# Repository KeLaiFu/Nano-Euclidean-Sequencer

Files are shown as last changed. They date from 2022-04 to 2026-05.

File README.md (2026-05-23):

# Nano-Euclidean-Sequencer
Eurorack adaption of an original kosmo module by instructables.com/member/ljbrackney. Current code is operational but needs some fine tuning.   

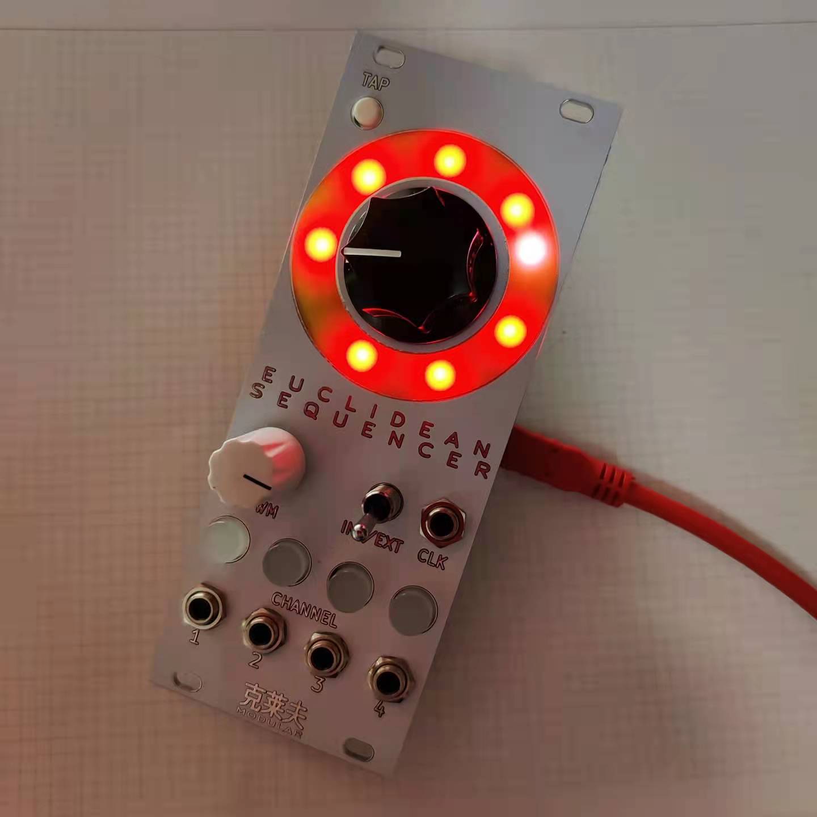
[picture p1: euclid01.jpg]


Current Status:
Hardware - finished.
Software - almost finished.

NOTE! If anyone wants to build this, please post a pull request or whatever they are here and I will dig up the latest firmware.

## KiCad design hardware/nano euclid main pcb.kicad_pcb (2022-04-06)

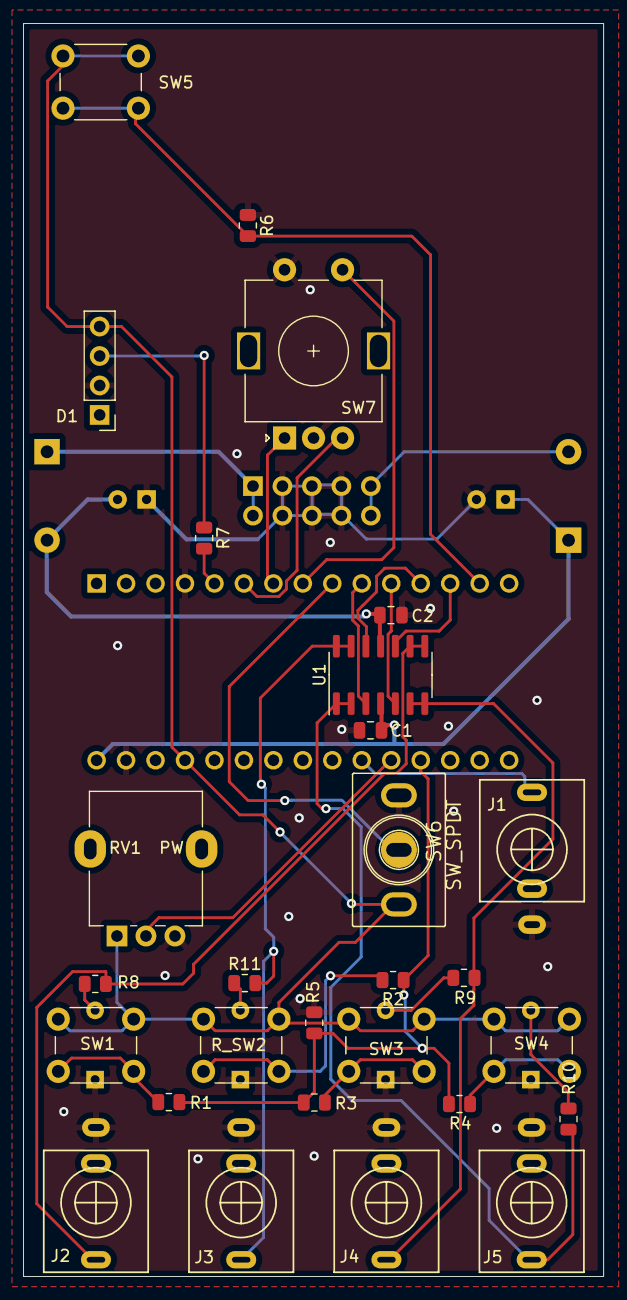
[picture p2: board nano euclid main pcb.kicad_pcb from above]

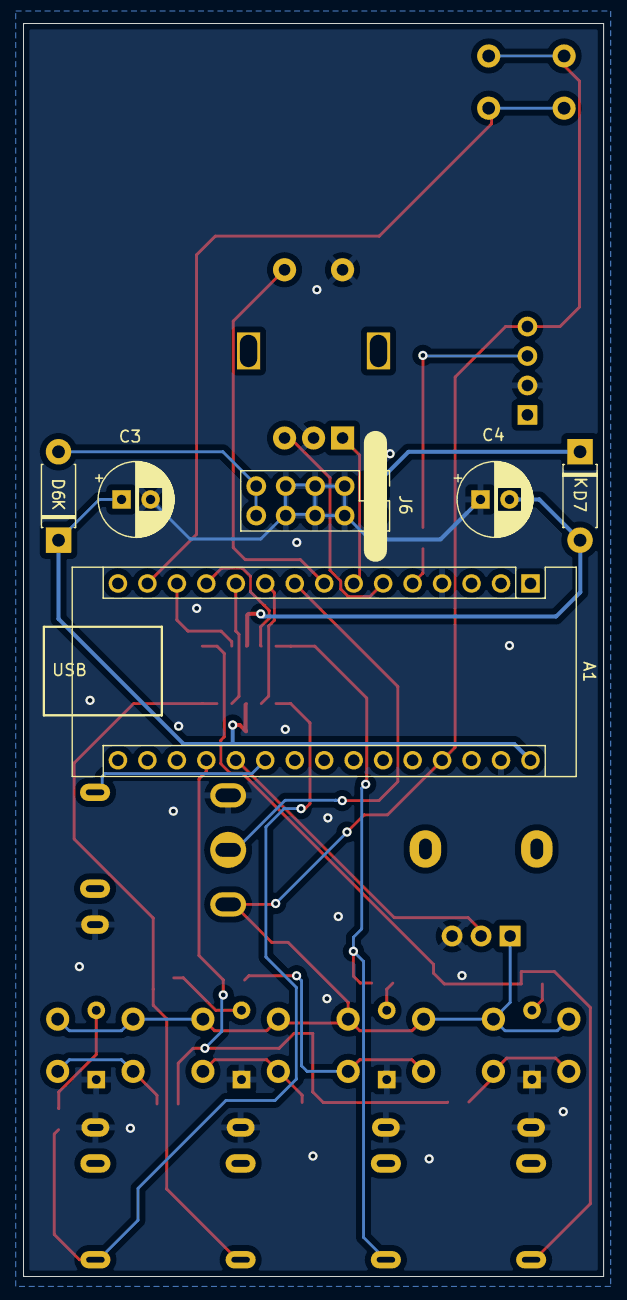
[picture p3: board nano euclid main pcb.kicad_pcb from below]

Board: 2 copper layers, 50.0 x 108.0 mm, 34 parts (6 on the bottom side), 32 nets.

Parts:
A1: Arduino_Nano_v3.x; Arduino_Nano
C1, C2: 0.1uF; C_0805_2012Metric
C3, C4: 10uF; CP_Radial_D6.3mm_P2.50mm
D1: NeoPixel_THT; PinHeader_1x04_P2.54mm_Vertical
D6, D7: 1N5817; D_DO-41_SOD81_P7.62mm_Horizontal
J1: CLOCK; PJ398SM
J2, J3, J4, J5: AudioJack2_Ground; PJ398SM
J6: Synth_power_2x5; PinHeader_2x05_P2.54mm_Vertical
R1, R2, R3, R4, R5, R6, R7, R8, R9, R10, R11: R; R_0805_2012Metric
RV1  PW: R_Potentiometer; Potentiometer_Alpha_RD901F-40-00D_Single_Vertical
R_SW2: SW_Push; SW_PUSH_LED_6mm
SW1, SW3, SW4: SW_Push; SW_PUSH_LED_6mm
SW5: SW_Push; SW_PUSH_6mm
SW6: SW_SPDT; SPDT_KIT
SW7: RotaryEncoder_Switch; RotaryEncoder_Alps_EC11E-Switch_Vertical_H20mm
U1: TL074; SOIC-14_3.9x8.7mm_P1.27mm

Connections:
+12V: A1.30 (VIN), C1.1, C3.1, D6.1 (K), U1.4 (V+)
-12V: C2.1, C4.2, D7.2 (A), U1.11 (V-)
GND: A1.4 (GND), A1.29 (GND), C1.2, C2.2, C3.2, C4.1, D1.2 (GND), J1.S, J2.S, J3.S, J4.S, J5.S, J6.3 (GND), J6.4 (GND), J6.5 (GND), J6.6 (GND), J6.7 (GND), J6.8 (GND), R5.2, R6.1, RV1 PW.3, R_SW2.4 (K), SW1.4 (K), SW3.4 (K), SW4.4 (K), SW6.1 (A), SW7.C, SW7.S2
unnamed: A1.5 (D2), R7.2
unnamed: A1.6 (D3), SW7.B
unnamed: A1.7 (D4), SW7.A
unnamed: A1.8 (D5), SW7.S1
unnamed: A1.9 (D6), SW6.2 (B)
unnamed: A1.10 (D7), U1.3 (+)
unnamed: A1.11 (D8), U1.5 (+)
unnamed: A1.12 (D9), U1.12 (+)
unnamed: A1.13 (D10), U1.10 (+)
unnamed: A1.14 (D11), R6.2, SW5.2
unnamed: A1.19 (A0), R1.1, R2.1, R3.1, R4.1, R5.1
unnamed: A1.20 (A1), RV1 PW.2
unnamed: A1.21 (A2), J1.T
unnamed: A1.27 (+5V), D1.4 (DIN), RV1 PW.1, R_SW2.1, SW1.1, SW3.1, SW4.1, SW5.1, SW6.3 (C)
unnamed: D1.3 (VDD), R7.1
unnamed: D6.2 (A), J6.9 (+12V), J6.10 (+12V)
unnamed: D7.1 (K), J6.1 (-12V), J6.2 (-12V)
unnamed: J2.T, R8.1, U1.8, U1.9 (-)
unnamed: J3.T, R11.2, U1.13 (-), U1.14
unnamed: J4.T, R9.2, U1.6 (-), U1.7
unnamed: J5.T, R10.2, U1.1, U1.2 (-)
unnamed: R1.2, SW1.2
unnamed: R2.2, R_SW2.2
unnamed: R3.2, SW3.2
unnamed: R4.2, SW4.2
unnamed: R8.2, SW1.3 (A)
unnamed: R9.1, SW3.3 (A)
unnamed: R10.1, SW4.3 (A)
unnamed: R11.1, R_SW2.3 (A)

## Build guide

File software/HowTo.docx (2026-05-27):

Compile, upload and run the code one time with the “Pre.ino” one .

This will result in the nano writing 16 patches to its EEPROM.

One patch will contain a pattern, the others are empty patches.

Next use the “After.ino” and compile, upload and run the code. This will program the Euclidean sequencer code into the nano which will be run each time you start up the nano.

The nano will read the patches from memory each time it starts and chooses the patch you saved last.

Upon startup the sequencer is in 'Pattern Length / Tempo Mode'.

When pressing the rotary encoder you can switch to the second mode, 'Num Pulse Mode'.

Press it again and the mode is 'Rotate Mode'.

Press again and the mode returns to 'Pattern Length / Tempo Mode'.

In 'Pattern Mode' rotating the encoder will increase or decrease the pattern length of the chosen trigger channel. Each time you change the length of the pattern a new fitting Euclidean pattern is generated depending on the number of pulses chosen (see below) for this pattern. Rotating the dial with the tap tempo / shift button pressed at the same time, will allow for changing tempo of the sequencer's internal clock.

In 'Num Pulse Mode' the encoder can be used to set the number of trigger pulses for the chosen trigger channel. The pulses will follow a Euclidean pattern.

In 'Rotate Mode' it is possible to shift the trigger pulse pattern accross the total length of the pattern.

Pressing the shift button and the rotary switch at the same time (…fill mode) will select the 'Program Mode'.

Using the rotary encoder's knob 1 of 16 memory cells can be selected.

- Pressing the trigger channel D button will store the current pattern of the selected trigger channel to the corresponding memory cell.

- Pressing the trigger channel A button will recall the patch pattern stored in the EEPROM memory cell and store it in the sequencer's active memory at the patch number selected with the rotary dial.

- Pressing the trigger channel B button will clear the patch in the eeprom the rotary encoder is set to. The pattern already in the working memory however will not be changed. Don't forget to save it if you like it. The LEDs will light up red for the locations containing a patch and green for the locations that are cleared. When in 'Program Mode' pressing the rotary switch will switch to 'Pattern Length / Tempo Mode'

To exit Programm mode press the main encoder.

Changed the slowest loop time to 2 sec per step for more slower beats possible.

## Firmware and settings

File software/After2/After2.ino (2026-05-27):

  /*
   *                                                                      
   *   Program:      Euclidean Rhythm Generator Kosmo/Eurorack  
   *   Author:       L J Brackney,                              
   *   Organization: Suncoast Polytechnical High School         
   *   Version:      1.0                                        
   *   Date:         11/21/2021                                 
   *                                                            
   *   Adapted by Jos Bouten, Jan ... Apr 2022              
   *   Added support for shift button, clock out, 4 function inputs
   *   - Added variable pattern length                        
   *   - To change the tempo the shift/tap tempo button needs to be pressed while   
   *     the rotary encoder is rotated.                                      
   *   - Changed all channel dependent variables into arrays.
   *   - Used capitals for constants, camel case for variables and function calls
   *   - Setting the speed depends on pressing the tap tempo button.
   *   - While setting the speed, the pattern leds show a white background pattern.
   *   - Added storing, recalling and clearing of patches in EEPROM.
   *   - The channel chosen last will be recalled on startup.
   *  2022-04-27: Whenever you change the pattern length, or change the number of Euclidean Rhythm pulses,
   *     a new euclidean pattern is generated and this pattern is started from its starting position
   *     for the active pattern.
   * 2022-04-29: The mode from which a jump into program mode is made is restored when leaving program mode.
   * 2022-05-05: Code adapted to function inputs using negative logic.
   *   
   *  Compile, upload and run the code one time with the INITIALIZE flag set.
   *  This will result in the nano writing 16 patches to its EEPROM.
   *  One patch will contain a pattern, the others are empty patches.
   *  Next comment out the line "#define INITIALIZE 1" and compile, upload 
   *  and run the code. This will program the Euclidean sequencer code into the nano 
   *  which will be run each time you start up the nano. The nano will read the patches
   *  from memory each time it starts and chooses the patch you saved last.
   *  
   *  Upon startup the sequencer is in 'Pattern Length / Tempo Mode'. When pressing the rotary encoder you can 
   *  switch to the second mode, 'Num Pulse Mode'. Press it again and the mode is 'Rotate Mode'.
   *  Press again and the mode returns to 'Pattern Length / Tempo Mode'.
   *  
  *  In 'Pattern Mode' rotating the encoder will increase or decrease the pattern length of the chosen trigger channel.
   *  Each time you change the length of the pattern a new fitting Euclidean pattern is generated depending on
   *  the number of pulses chosen (see below) for this pattern.
   *  Rotaring the dial with the tap tempo / shift button pressed at the same time, will allow for changing 
   *  tempo of the sequencer's internal clock. 
   *  In 'Num Pulse Mode' the encoder can be used to set the number of trigger pulses for the chosen trigger channel. 
   *  The pulses will follow a Euclidean pattern.
   *  In 'Rotate Mode' it is possible to shift the trigger pulse pattern accross the total length of the pattern.
   *  
   *  Pressing the shift button and the rotary switch at the same time will select the 'Program Mode'.
   *  Using the rotary encoder's knob 1 of 16 memory cells can be selected.
   *  Pressing the trigger channel D button will store the current pattern of the selected trigger channel to the corresponding memory cell.
   *  Pressing the trigger channel A button will recall the patch pattern stored in the EEPROM memory cell and store it in 
   *  the sequencer's active memory at the patch number selected with the rotary dial.
   *  Pressing the trigger channel B button will clear the patch in the eeprom the rotary encoder is set to. 
   *  The pattern already in the working memory however will not be changed. Don't forget to save it is you like it.
   *  
   *  The leds will light up red for the locations containing a patch and green for the locations that are cleared.
   *  When in 'Program Mode' pressing the rotary switch will switch to 'Pattern Length / Tempo Mode'.
   *  
   *  2022-02-27: some changes to hardware and software
   *  - deactivated pattern length change menu because this is hardly ever used and 
   *    is a nuisance to have to click through
   *  - added tempo change to rotate and pulse number menu.
   *  - adapted ext clock in and func in to positive logic after hardware change
   *  - changed the range of the pulse width knob so that the output pulses range from 
   *    about 10% to 99% of the clock cyle time
   *  - changed the duty cycle of the clock out to be fixed at 50%
   */

// Show some debug info on the serial port.
#define DEBUG 1

// Activate this if you allow pattern length change
// #define ALLOW_PATTERN_LENGTH_CHANGE 1


// Run program once using INITIALIZE to set some initial values in the EEPROM
//#define INITIALIZE 1

// Use the switches below to make the brightness of the neopixel oscillate.

#define LED_FX 1 // Oscillate LEDs in all modes except PROGRAM_MODE.
//#define LED_FX_BLACK 1 // When set the intensity will fall back to 0, otherwise to 1.
//#define PATCH_MEMORY_LED_FX 1 // Also oscillate LED intensity in PROGRAM_MODE

#include <Adafruit_NeoPixel.h>    // Include Adafruit_NeoPixel library
#include <Encoder.h>              // Include rotary encoder library
#include <EEPROM.h>

/* 
    EEPROM memory layout:
    0: selectedTriggerChannel
    1: default programNumber
    2: memoryCellsInUse
    3: delayTime
    4: 16 patches:
     - pulses[5]
     - channelPattern[5]
     - patternLength[5]

*/

Encoder myEnc(3, 4);              // Attach rotary encoder to digital pins 3 and 4

#define PIXEL_PIN      2          // Attach NeoPixel ring to digital pin 2
#define PROG_PIN       5          // Attach rotary encoder switch to digital pin 5
#define CLOCK_SOURCE_PIN 6          // Attach external clock select switch to digital pin 6
#define TRIG_D_PIN     7          // Attach the four drum/voice trigger output pins to 
#define TRIG_C_PIN     8          //   digital pins 7-10.  I mixed up two wires when
#define TRIG_B_PIN     9          //   assembling the modules, and it was easier to
#define TRIG_A_PIN    10          //   swap pins 7 and 10 than to resolder things. :)
#define BUTTON_PIN    A0          // The trigger select buttons are on a voltage divider attached to A0
#define PWM_POT_PIN   A1          // The pulse width potentiometer is attached to analog pin A1
#define RESET_PIN     12          // RESET_PIN CV in on D12
#define NUM_CHANNELS 4

#define SHIFT_PIN     11          // Shift Function button on D11 
#define ON LOW
#define OFF HIGH

// Modes you can choose by pressing the rotary encoder's button.
#define PATTERN_LENGTH_MODE 1 // also used as "pulse length mode"
#define NUM_PULSE_MODE      2
#define ROTATE_MODE         3
#define PROGRAM_MODE        4 // Allows to store patterns in EEPROM or to recall them. This mode can only be reached 
                              // pressing the shift button AND the rotary encoder button.
#define MAX_MODE            3 // Note, we do not count PROGRAM_MODE here.         

#define F1_PIN A7            // Function F1 in
#define F2_PIN A6            // Function F2 in
#define F3_PIN A5            // Function F3 in
#define F4_PIN A4            // Function F4 in
#define SEQ_CLOCK_OUT_PIN A3 // Sequencer clock out (whether internal or from external source)
#define EXT_CLOCK_IN_PIN  A2 // Ext Clock in

#define HALF_DAC_RANGE 500

#define NUM_NEOP_LEDS 16     // The number of LEDs in the neopixel wheel.

#define MAX_DELAY_TIME 1000   // Limit the slowest loop time to 1 sec per step.
                             // Change if you want slower tempos.          

#define NR_OF_MEMORY_CELLS NUM_NEOP_LEDS

#define EEPROM_BASE_ADDRESS 0

#define TRIG_A 3
#define TRIG_B 2
#define TRIG_C 1
#define TRIG_D 0

#define MAX_ADC_VALUE 1000 // This number was determined empirically.

#define CHECK_BIT(var, pos) ((var) & (1 << (pos)))

char CHANNEL_NAMES[4] = {'D', 'C', 'B', 'A'};

char msg[255];

static int step[4];               // The active step for each trigger channel.
struct Patch {
  int pulses[4];                  // The number of pulses to be generated for each of the 4 triggers.
  int patternLength[4];           // The pattern length for each trigger output.
  unsigned int channelPattern[4]; // The pattern of Euclidean distributed pulses,
};

Patch emptyPatch;
Patch currentPatch;               // The patch the sequencer is playing.

Patch patches[NR_OF_MEMORY_CELLS];
unsigned int delayTime  = 125;    // The time between steps persists in each loop.
unsigned int memoryCellsInUse = 0;
int chosenPatchNumber = 0;
int candidatePatchNumber = 0;
int selectedTriggerChannel = -1;

Adafruit_NeoPixel pixels(NUM_NEOP_LEDS, PIXEL_PIN, NEO_GRB + NEO_KHZ800); // Set up the NeoPixel ring

// Fill the dots one after the other with a color.
void colorWipe(uint32_t c, uint8_t wait, int direction = 0) {
  if (direction == 0) {
    for (uint16_t i = 0; i < pixels.numPixels(); i++) {
      pixels.setPixelColor(i, c);
      pixels.show();
      delay(wait);
    } 
  } else {
    for (uint16_t i = pixels.numPixels()-1; i > 0; i--) {
      pixels.setPixelColor(i, c);
      pixels.show();
      delay(wait);
    }
  }
}

// The Euclid function returns an unsigned integer whose bits reflect a Euclidean rhythm of
// "pulses" spread across "patternLength[]."  There are several ways to implement this, but 
// here an adapted version of algorithm described at:
// https://www.computermusicdesign.com/simplest-euclidean-rhythm-algorithm-explained/
// is used.

unsigned int euclid(Patch thisPatch, int channelNumber) {
  int bucket = 0;
  unsigned int number = 0;                                           // Number is the number of pulses that have been allocated so far.
  for (int i = 0; i < thisPatch.patternLength[channelNumber]; i++) { // Cycle through all of the possible steps in the sequence.
    bucket = bucket + thisPatch.pulses[channelNumber];               // Fill a "bucket" with the number of pulses to be allocated.
    if (bucket >= thisPatch.patternLength[channelNumber]) {          // If the bucket exceeds the maximum number of steps then "empty
      bucket = bucket - thisPatch.patternLength[channelNumber];      // the bucket" by setting the i-th bit in the sequence and
      number |= 1 << i;                                              // Refill the now empty bucket with the remainder.
    }
  }
  return number; // Return the sequence encoded as the bits set in Number.
}

// The rotateLeft function shifts the bits in an unsigned integer by one place. Any bit that falls
// off to the left (of the most significant bit) is shifted around to become the new least
// significant bit.  For our purposes, this means that we can rotate the Euclidean Rhythm clockwise
// on the ring.
void rotateLeft(Patch &thisPatch, int channelNumber) {
  int DROPPED_MSB;                        // Need to keep track of any bits dropped off the left
  DROPPED_MSB = (thisPatch.channelPattern[channelNumber] >> (thisPatch.patternLength[channelNumber] - 1)) & 1; // aka the old most significant bit
  // Shift all the bits in Pattern to the left by 1 and add back in the new least significant bit if needed.
  thisPatch.channelPattern[channelNumber] = (thisPatch.channelPattern[channelNumber] << 1) | DROPPED_MSB; 
}

// The rotateRight function shifts the bits in an unsigned integer by one place. Any bit that falls
// off to the right (of the least significant bit) is shifted around to become the new most
// significant bit.  For our purposes, this means that we can rotate the Euclidean Rhythm counter
// clockwise on the ring.
void rotateRight(Patch &thisPatch, int channelNumber) {
  int DROPPED_LSB;                        // Need to keep track of any bits dropped off the right
  DROPPED_LSB = thisPatch.channelPattern[channelNumber] & 1;              // aka the old least signficant bit.
  thisPatch.channelPattern[channelNumber] = (thisPatch.channelPattern[channelNumber] >> 1) & (~(1 << (thisPatch.patternLength[channelNumber] - 1))); // Shift all the bits in Pattern to the right by 1.
  thisPatch.channelPattern[channelNumber] = thisPatch.channelPattern[channelNumber] | (DROPPED_LSB << (thisPatch.patternLength[channelNumber] - 1)); // Tack the old LSB onto the new MSB if needed
}

// checkButtons and checkProgramButtons decode the voltage values from the button voltage divider circuit. The values here
// assume that 1k, 2.2k, 4.7k and 10k resistors are switched in line with a 5V source and dropped
// across a 10k resistor before going into the analog input channel. The ranges should be big
// enough to accommodate resistor variation, but if a button doesn't switch to the trigger as expected
// you should Serial.println(Buttons) and adjust the ranges as needed for your circuit.

int checkProgramButtons(int &selectedProgramButtonName) {
  // Note: the selectedProgramButtonName will only change if a button is pressed.
  // Read the voltage divider output.
  int buttonValue = analogRead(BUTTON_PIN); 
  //  Determine whether button A, B or D was pressed.
  if ((buttonValue > 0.40 * MAX_ADC_VALUE) && (buttonValue < 0.60 * MAX_ADC_VALUE)) { 
    selectedProgramButtonName = TRIG_D; // Button D is pressed.
    return 1;
  }
  if ((buttonValue > 0.75 * MAX_ADC_VALUE) && (buttonValue < 0.84 * MAX_ADC_VALUE)) {
    selectedProgramButtonName = TRIG_B; // Button B is pressed.
    return 1;
  }
  if (buttonValue > 0.85 * MAX_ADC_VALUE) { 
    selectedProgramButtonName = TRIG_A; // Button A is pressed.
    return 1;
  }
  selectedProgramButtonName = -1;
  return 0;
}

bool checkButtons(int &selectedChannel, int shiftButton) {
  // Note: the selectedChannel will only change if a button is pressed.
  static int previousSelectedChannel = -1;
  static bool change = false;

  // If no button was pressed, return the input parameter unchanged.
  // Pattern/trigger D will be shown in red.
  // Pattern/trigger C will be shown in green.
  // Pattern/trigger B will be shown in blue.
  // Pattern/trigger A will be shown in yellow .

  int buttonValue = analogRead(BUTTON_PIN); 
  // Read the voltage divider output and only change the selectedChannel if shiftButton is not pressed.
  if (shiftButton == 0) {       
    if ((buttonValue > 0.40 * MAX_ADC_VALUE) && (buttonValue < 0.60 * MAX_ADC_VALUE)) selectedChannel = TRIG_D; // Select pattern/trigger D if the first button is pressed
    if ((buttonValue > 0.64 * MAX_ADC_VALUE) && (buttonValue < 0.73 * MAX_ADC_VALUE)) selectedChannel = TRIG_C; // Select pattern/trigger C if the second button is pressed
    if ((buttonValue > 0.75 * MAX_ADC_VALUE) && (buttonValue < 0.84 * MAX_ADC_VALUE)) selectedChannel = TRIG_B; // Select pattern/trigger B if the third button is pressed
    if (buttonValue > 0.85 * MAX_ADC_VALUE) selectedChannel = TRIG_A;   // Select pattern/trigger A if the last button is pressed
    if (previousSelectedChannel != selectedChannel) {
      previousSelectedChannel = selectedChannel;
      change = true;
    } else {
      change = false;
    }
  }
  return change;
}

void ClearNeoPixelPattern() {
  // Erases all lights on the NeoPixel in preparation for an updated pattern to be displayed.
  for (int i = 0; i < NUM_NEOP_LEDS; i++) {         // Step through each pixel in the ring and
    pixels.setPixelColor(i, pixels.Color(0, 0, 0)); // turn each pixel off.
  }
  pixels.show();                                    // Update the pixels displayed on the ring.
}

void getCursorColor(int mode, int &R, int &G, int &B) {
  switch (mode) { 
    case PATTERN_LENGTH_MODE: R = 2; G = 2; B = 0; break; // Violet = Pulses, White = Rotation      
    case NUM_PULSE_MODE:      R = 5; G = 0; B = 5; break; // Yellow = Length
    case ROTATE_MODE:         R = 5; G = 5; B = 5; break; // Use the mode to determine the color.
    
  }  
}
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
  void loop() {
    
// Activate this if you allow pattern length change
    #ifdef ALLOW_PATTERN_LENGTH_CHANGE
      static int mode = PATTERN_LENGTH_MODE;
    #else
      static int mode = NUM_PULSE_MODE;
    #endif    
    static int prevMode = 0;
    static long mode1Pos  = 0;              // The last encoder position in mode 1 is stored for a future return to that mode.
    static int prevExtClk = 0;              // Store the previous External Clock Pulse value for transition checking.
    static unsigned long thisTime;          // Prepare to query the Nano's clock.
    static unsigned long prevTime = 0;      // Keep track of how much time elapses between loops.
    static long oldPosition;                // Keep track of the previous encoder count.
    static bool prevProg;                   // Keep track of the previous encoder switch state.
    static bool prog;                       // Prepare to read the current encoder switch state.
    static int prevF1 = 0;                  // Keep track of the value of the F1 CV input.
    static int prevF2 = 0;                  // Keep track of the value of the F2 CV input.
    static int prevF3 = 0;                  // Keep track of the value of the F3 CV input.
    static int prevF4 = 0;                  // Keep track of the value of the F4 CV input.
    static int prevResetPinIn = 0;          // Keep track of the value of the Reset in CV input.
    int deltaResetPinIn = 0;                // Keep track of the value of the Reset in CV input.

    bool triggered = false;                     // Assume that no new step is going to occur this loop.
    long newPosition = myEnc.read();            // Read the current number of encoder counts.
    int triggerWidthPotValue = analogRead(PWM_POT_PIN); // Read the trigger pulse width potentiometer value.
    int extClkV    = analogRead(EXT_CLOCK_IN_PIN);   // Read the external clock input.
    int f1In       = analogRead(F1_PIN); // Read the Func 1 input, will return a low value if no signal is present, else a high value
    int f2In       = analogRead(F2_PIN); // Read the Func 2 input
    int f3In       = analogRead(F3_PIN); // Read the Func 3 input
    int f4In       = analogRead(F4_PIN); // Read the Func 4 input
    int resetPinIn = digitalRead(RESET_PIN);    // Read the external RESET_PIN input
    int shiftButton = digitalRead(SHIFT_PIN);   // Read the shift button (will be HIGH when pressed);
    int programButtonName = -1;
    int programButtonValue;
    static int prevProgramButtonValue = 0;
    boolean change = false;
    int R = 0, G = 0, B = 0;
    

    if (mode == PROGRAM_MODE) {
      programButtonValue = checkProgramButtons(programButtonName); // Find out whether Trig A, B or D was pressed.
      if (programButtonValue == 0) { // No button was pressed.
        prevProgramButtonValue = 0;
      }
    } else {
      change = checkButtons(selectedTriggerChannel, shiftButton);// Query the trigger buttons and update the active trigger if needed.
      if (change) { // Remember the channel chosen (this will be recalled when powering up).
        writeTriggerChannelToEEPROM(selectedTriggerChannel);
      }
    }

    prevProg = prog;                          // Store the last encoder switch position.
    prog     = digitalRead(PROG_PIN);         // Get the current encoder switch position.

    thisTime = millis();                      // Get the current Nano clock value in msec.

    if ((prog == true) && (prevProg == false)) { // If the encoder switch was just pressed, we need to switch modes.
      if (mode == 1) mode1Pos = newPosition;     // Store the current encoder position for a future return to that mode.
      if (shiftButton) {                         // If the shift button is pressed as well, then we start the program mode.
        prevMode = mode;
        mode = PROGRAM_MODE;
      } else {
        if (mode == PROGRAM_MODE) {
          mode = prevMode;                       // Return to mode from which we jumped into program mode
        } else {
          mode++;                                // Cycle to the next mode.
          if (mode > MAX_MODE) 
            #ifdef ALLOW_PATTERN_LENGTH_CHANGE
              mode = PATTERN_LENGTH_MODE; 
            #else
              mode = NUM_PULSE_MODE;
            #endif
          if (mode == PATTERN_LENGTH_MODE) {                       // Restore the encoder position when last in the current mode.
            myEnc.write(mode1Pos);
            newPosition = mode1Pos;
          }
        }
      }
      oldPosition = newPosition;                 // The current encoder position will be the old position next loop.
    }

    ClearNeoPixelPattern();                      // Clear the NeoPixel ring in preparation for any changes to the pattern.

    // Respond to function CV inputs.
    // Let the left top Func input (Func 1) change the left most
    // trigger output (Trig A).
    //if ((f1In > HALF_DAC_RANGE) && (prevF1 < HALF_DAC_RANGE)) {
    //  rotateLeft(currentPatch, TRIG_D);
    //}
    //prevF1 = f1In;
//
//    if ((f2In > HALF_DAC_RANGE) && (prevF2 < HALF_DAC_RANGE)) {
//      rotateLeft(currentPatch, TRIG_C);
//    }
//    prevF2 = f2In;
//
//    if ((f3In > HALF_DAC_RANGE) && (prevF3 < HALF_DAC_RANGE)) {
//        rotateLeft(currentPatch, TRIG_B);
//    }
 //   prevF3 = f3In;
//
 //   if ((f4In > HALF_DAC_RANGE) && (prevF4 < HALF_DAC_RANGE)) {
   //   rotateLeft(currentPatch, TRIG_A);
   // }
   // prevF4 = f4In;

    // Reset on positive going edges of the reset pin.
   // deltaResetPinIn = resetPinIn - prevResetPinIn;
   // if (deltaResetPinIn == 1) {
     // for (int triggerChannel = 0; triggerChannel < 4; triggerChannel++) {
       //   step[triggerChannel] = 0;
    //  }
    //  prevResetPinIn = 1;
    // } 
    //if (deltaResetPinIn == -1) {
    //  prevResetPinIn = 0;
   // }
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

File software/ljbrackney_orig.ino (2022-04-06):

/*-----------------------------------------------------------------------* 
 *                                                                       *
 *   Program:      Euclidean Rhythm Generator Kosmo/Eurorack             *
 *   Author:       L J Brackney,                                         *
 *   Organization: Suncoast Polytechnical High School                    *
 *   Version:      1.0                                                   *
 *   Date:         11/21/2021                                            *
 *                                                                       *
 *-----------------------------------------------------------------------*/

#include <Adafruit_NeoPixel.h>    // Include Adafruit_NeoPixel library
#include <Encoder.h>              // Include rotary encoder library

Encoder myEnc(3, 4);              // Attach rotary encoder to digital pins 3 and 4

#define PixelPin    2             // Attach NeoPixel ring to digital pin 2
#define ProgPin     5             // Attach rotary encoder switch to digital pin 5
#define ClkPin      6             // Attach external clock select switch to digital pin 6
#define Trig1Pin   10             // Attach the four drum/voice trigger output pins to 
#define Trig2Pin    8             //   digital pins 7-10.  I mixed up two wires when
#define Trig3Pin    9             //   assembling the modules, and it was easier to
#define Trig4Pin    7             //   swap pins 7 and 10 than to resolder things. :)
#define TapPin     11             // Attach a push button for the "tap tempo" feature to digital pin 11
#define ButtonPin  A0             // The trigger select buttons are on a voltage divider attached to A0
#define PotPin     A1             // The pulse width potentiometer is attached to analog pin A1
#define ExtClkPin  A2             // The external clock CV is attached to analog pin A2

#define NumSteps   16             // The program assumes 16 beat sequences, but it can be changed here

int  Part = 1;                    // The current part/trigger is initially set to 1.

Adafruit_NeoPixel pixels(NumSteps, PixelPin, NEO_GRB + NEO_KHZ800);  // Set up the NeoPixel ring


// The Euclid function returns an unsigned integer whose bits reflect a Euclidean rhythm of
// "Numpulses" spread across "NumSteps."  There are several ways to implement this, but I
// adapted the algorithm described at:
//   https://www.computermusicdesign.com/simplest-euclidean-rhythm-algorithm-explained/

unsigned int Euclid(int NumPulses) {
  unsigned int Number = 0;              // Number is the number of pulses that have been allocated so far
  for (int i=0; i<NumSteps; i++) {      // Cycle through all of the possible steps in the sequence
    int bucket = bucket + NumPulses;    // Fill a "bucket" with the number of pulses to be allocated
    if (bucket >= NumSteps) {           // If the bucket exceeds the maximum number of steps then "empty
      bucket = bucket - NumSteps;       // the bucket" by setting the "ith" bit in the sequence and
      Number |= 1 << i;                 // refill the now empty bucket with the remainder.
    }
  }
  return(Number);                       // Return the sequence encoded as the bits set in Number
}


// The RotateLeft function shifts the bits in an unsigned integer by one place.  Any bit that falls
// off to the left (of the most significant bit) is shifted around to the become the new least
// significant bit.  For our purposes, this means that we can rotate the Euclidean Rhythm clockwise
// on the ring. 

unsigned int RotateLeft(unsigned int Number) {
  int DROPPED_MSB;                              // Need to keep track of any bits dropped off the left
  DROPPED_MSB = (Number >> NumSteps-1) & 1;     // aka the old most significant bit
  Number = (Number << 1) | DROPPED_MSB;         // Shift all the bits in Number to the left by 1 and
  return(Number);                               // add back in the new least significant bit if needed
}


// The RotateRight function shifts the bits in an unsigned integer by one place.  Any bit that falls
// off to the right (of the least significant bit) is shifted around to the become the new most
// significant bit.  For our purposes, this means that we can rotate the Euclidean Rhythm counter
// clockwise on the ring.

unsigned int RotateRight(unsigned int Number) {
  int DROPPED_LSB;                               // Need to keep track of any bits dropped off the right
  DROPPED_LSB = Number & 1;                      // aka the old least signficant bit
  Number = (Number >> 1) & (~(1 << NumSteps-1)); // Shift all the bits in Number to the right by 1
  Number = Number | (DROPPED_LSB << NumSteps-1); // Tack the old LSB onto the new MSB if needed
  return(Number);
}


// CheckButtons decodes the voltage values from the button voltage divider circuit.  The values here
// assume that 1k, 2.2k, 4.7k and 10k resistors are switched in line with a 5V source and dropped
// across a 10k resistor before going into the analog input channel.  The ranges should be big
// enough to accomodate resistor variation, but if a button doesn't switch to the trigger as expected
// you should Serial.println(Buttons) and adjust the ranges as needed for your circuit.

int CheckButtons() {
  int Buttons = analogRead(ButtonPin);         // Read the voltage divider output
  if ((Buttons>480)&&(Buttons<520)) Part = 1;  // Select pattern/trigger 1 if the first button is pressed
  if ((Buttons>580)&&(Buttons<620)) Part = 2;  // Select pattern/trigger 2 if the second button is pressed
  if ((Buttons>680)&&(Buttons<720)) Part = 3;  // Select pattern/trigger 3 if the third button is pressed
  if (Buttons>800) Part = 4;                   // Select pattern/trigger 4 if the last button is pressed
}


// ClearPattern erases all lights on the NeoPixel in preparation for an updated pattern to be displayed

void ClearPattern() {
  for (int i=0; i<NumSteps; i++)                   // Step through each pixel in the ring
    pixels.setPixelColor(i, pixels.Color(0,0,0));  // turn each pixel off
  pixels.show();                                   // Update the pixels displayed on the ring
}


// BitPattern displays a Euclidean pattern associated with the bits set in Number.  The color of the
// pattern is dictated by channel number "Chan."  You can change the ring colors to match the buttons
// and output LEDs you use in your build here.
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
